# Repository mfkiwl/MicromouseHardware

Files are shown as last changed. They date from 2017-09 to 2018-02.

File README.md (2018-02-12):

# MicromouseHardware
This is the Hardware design for my micromouse. I will be participating in the UC San Diego's IEEE Micromouse competition 
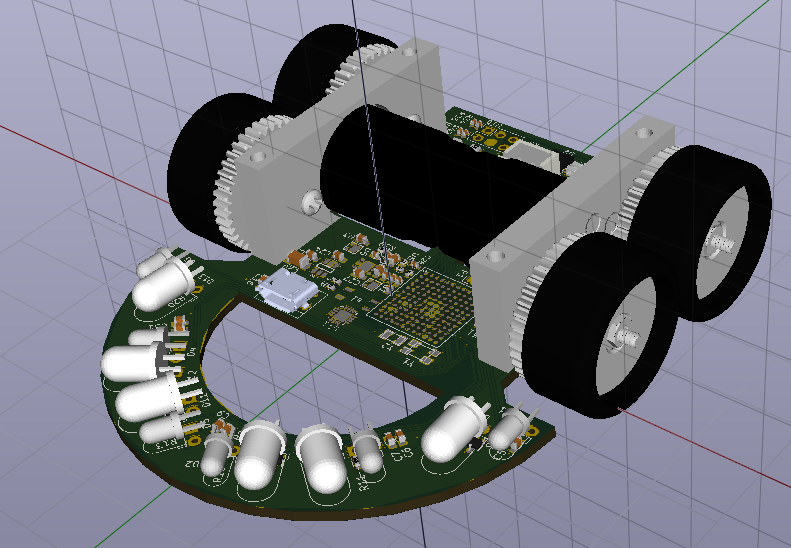
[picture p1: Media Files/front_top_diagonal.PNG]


 More images can be found [here](https://github.com/yyekalo/MicromouseHardware/tree/master/Media%20Files)

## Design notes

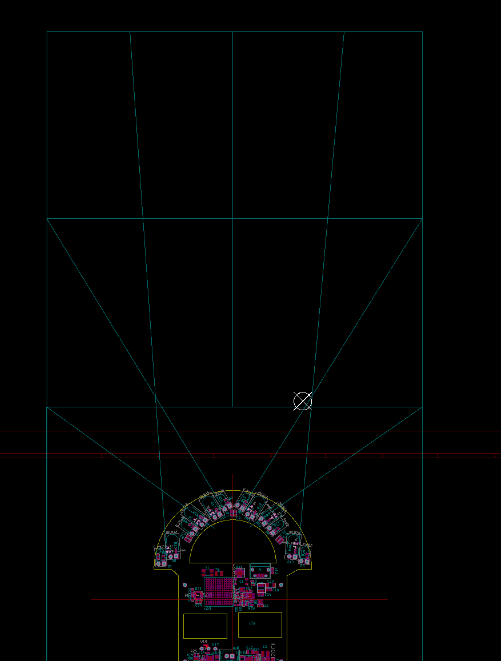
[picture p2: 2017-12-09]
IR-SENSORS direction.PNG

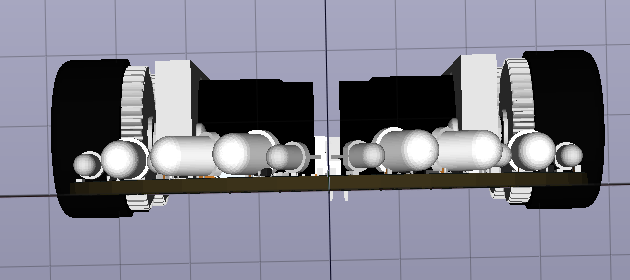
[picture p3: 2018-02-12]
Media Files/front.PNG

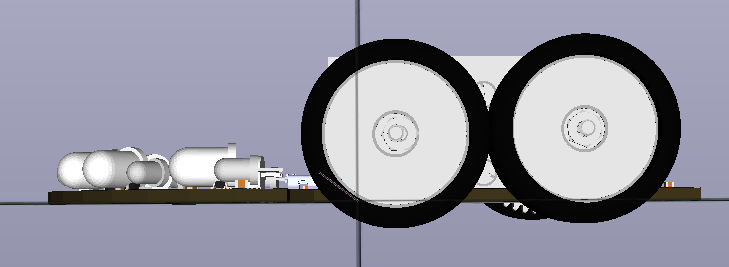
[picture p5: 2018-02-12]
Media Files/side.PNG

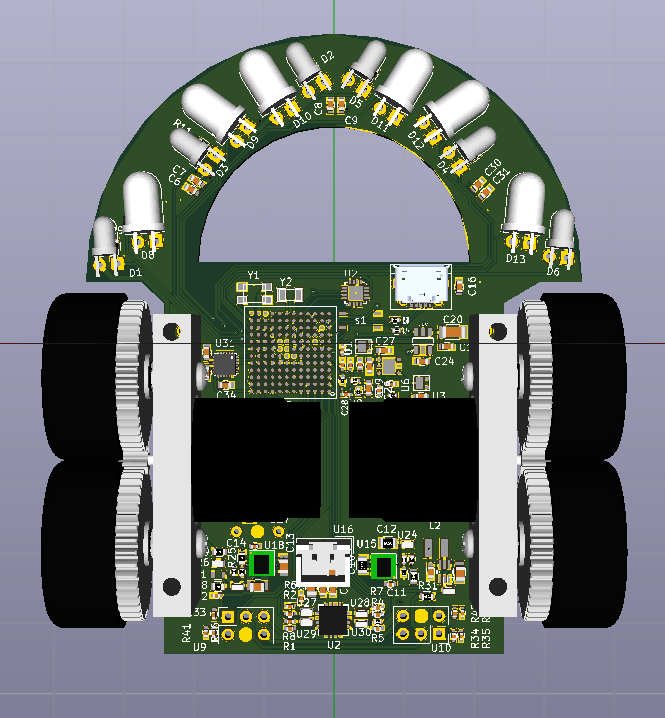
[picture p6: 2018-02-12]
Media Files/top.PNG

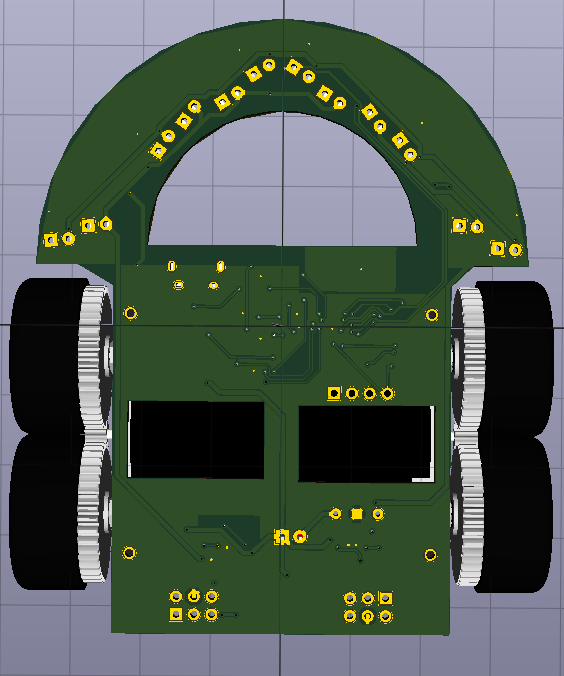
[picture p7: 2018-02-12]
Media Files/bottom.PNG

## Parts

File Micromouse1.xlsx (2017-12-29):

Proj: | None |  |  |  |  |  | Board Qty: | 100
Co.: | None |  |  |  |  |  | Total Cost: | $0.00 |  |  |  | $0.00
Date: | 2017-12-08 21:41:36 |  |  |  |  |  | Unit Cost: | $0.00 |  |  |  | 0
Global Part Info |  |  |  |  |  |  |  |  | Digi-Key
Refs | Value | Desc | Footprint | Manf | Manf# | Qty | Unit$ | Ext$ | Avail | Purch | Unit$ | Ext$ | Cat#
C1 | 100uF |  |  |  | RNE1C101MDS1PX | 0 | $0.00 | $0.00
C10 | 10uF |  | micromouse:R_0805 |  | GRM21BR60J106ME19L | 0 | $0.00 | $0.00 | 1786897 |  | $0.00 | $0.00 | 490-1718-1-ND (http://www.digikey.com/product-detail/en/murata-electronics-north-america/GRM21BR60J106ME19L/490-1718-1-ND/587425)
C11,C14 | 3300pF |  | micromouse:C_0402 |  | GRM033R70J332KA01D | 0 | $0.00 | $0.00
C12 | 22uF |  | micromouse:R_0805 |  | GRM21BC80G226ME39L | 0 | $0.00 | $0.00 | NonStk |  | $0.00 | $0.00 | 490-6464-1-ND (http://www.digikey.com/product-detail/en/murata-electronics-north-america/GRM21BC80G226ME39L/490-6464-1-ND/3845661)
C13 | 10uF |  | micromouse:C_0805 |  | GRM21BR60J106ME19L | 0 | $0.00 | $0.00 | 1786897 |  | $0.00 | $0.00 | 490-1718-1-ND (http://www.digikey.com/product-detail/en/murata-electronics-north-america/GRM21BR60J106ME19L/490-1718-1-ND/587425)
C15 | 22uF |  | micromouse:C_0805 |  | GRM21BC80G226ME39L | 0 | $0.00 | $0.00 | NonStk |  | $0.00 | $0.00 | 490-6464-1-ND (http://www.digikey.com/product-detail/en/murata-electronics-north-america/GRM21BC80G226ME39L/490-6464-1-ND/3845661)
C16,C18,C19,C24,C27,C29 | 2.2uF |  | micromouse:C_0603 |  | DNP | 0 | $0.00 | $0.00
C17,C21,C22,C26,C28 | 0.1uF |  | micromouse:C_0402 |  | DNP | 0 | $0.00 | $0.00
C2 | 10uF |  | Capacitors_SMD:C_0805 |  | C2012X5R1C106M | 0 | $0.00 | $0.00
C20 | 100uF |  | micromouse:C_1206 |  | DNP | 0 | $0.00 | $0.00
C23,C25 | 10nF |  | micromouse:C_0402 |  | DNP | 0 | $0.00 | $0.00
C3 | 0.01uF |  |  |  | GRM188R71E103KA01D | 0 | $0.00 | $0.00 | 1221077 |  | $0.00 | $0.00 | 490-1520-1-ND (http://www.digikey.com/product-detail/en/murata-electronics-north-america/GRM188R71E103KA01D/490-1520-1-ND/587861)
C32 | 10nF |  | Capacitors_SMD:C_0603 |  | DNP | 0 | $0.00 | $0.00
C35 | 2.2uF |  | Capacitors_SMD:C_0402 |  | GRM155R61A225KE95D | 0 | $0.00 | $0.00 | 31659 |  | $0.00 | $0.00 | 490-10451-1-ND (http://www.digikey.com/product-detail/en/murata-electronics-north-america/GRM155R61A225KE95D/490-10451-1-ND/5026361)
C36 | 10uF |  | Capacitors_SMD:C_0603 |  | GRM188R60J106ME47D | 0 | $0.00 | $0.00
C37 | 10uF |  | Capacitors_SMD:C_0805 |  | C0805C106K8PACTU | 0 | $0.00 | $0.00 | 1355633 |  | $0.00 | $0.00 | 399-4925-1-ND (http://www.digikey.com/product-detail/en/kemet/C0805C106K8PACTU/399-4925-1-ND/1090920)
C4 | 0.1uF |  | Capacitors_SMD:C_0603 |  | C1608X7R1E104K | 0 | $0.00 | $0.00
C5,C33 | 0.1uF |  | Capacitors_SMD:C_0603 |  | DNP | 0 | $0.00 | $0.00
C6-C9,C30,C31,C34 | C |  | Capacitors_SMD:C_0603 |  | DNP | 0 | $0.00 | $0.00
D1-D6 | ~ |  | micromouse:IR_Reciver |  | TEFT4300 | 0 | $0.00 | $0.00 | 5570 |  | $0.00 | $0.00 | 751-1041-ND (http://www.digikey.com/scripts/DkSearch/dksus.dll?WT.z_header=search_go&lang=en&keywords=TEFT4300%20)
D8-D13 | ~ |  | micromouse:IR_Emitter |  | SFH 4545 | 0 | $0.00 | $0.00
J1 | USB_B |  | micromouse:USB_Micro-B |  | DNP | 0 | $0.00 | $0.00
L1 | L |  | Inductors_SMD:L_0603 |  | BRL1608T100M | 0 | $0.00 | $0.00 | 73032 |  | $0.00 | $0.00 | 587-2895-1-ND (http://www.digikey.com/product-detail/en/taiyo-yuden/BRL1608T100M/587-2895-1-ND/2649015)
L2 | 4.7uH |  | Inductors_NEOSID:Neosid_Inductor_SM-NE29_SMD1008 |  | LQM2HPN4R7MGCL | 0 | $0.00 | $0.00 | 16254 |  | $0.00 | $0.00 | 490-7783-1-ND (http://www.digikey.com/product-detail/en/murata-electronics-north-america/LQM2HPN4R7MGCL/490-7783-1-ND/4357984)
P1 | CONN_01X4 |  | Socket_Strips:Socket_Strip_Straight_1x04_Pitch2.54mm |  | DNP | 0 | $0.00 | $0.00
Q1-Q6 | Q_NMOS_DGS |  | micromouse:DMG1012UW |  | DMG1012UW | 0 | $0.00 | $0.00 | 49178 |  | $0.00 | $0.00 | DMG1012UW-7DICT-ND (http://www.digikey.com/product-detail/en/diodes-incorporated/DMG1012UW-7/DMG1012UW-7DICT-ND/2183242)
R1,R2,R4 | 0 |  | Capacitors_SMD:C_0402 |  | MCS04020Z0000ZE000 | 0 | $0.00 | $0.00
R15-R20 | 0.75 |  | micromouse:C_0402 |  | ERJ-2BQFR75X | 0 | $0.00 | $0.00
R21 | 150K |  | micromouse:R_0402 |  | CRCW0402150KFKED | 0 | $0.00 | $0.00 | 315184 |  | $0.00 | $0.00 | 541-150KLCT-ND (http://www.digikey.com/product-detail/en/vishay-dale/CRCW0402150KFKED/541-150KLCT-ND/1183369)
R22,R26 | 10k |  | micromouse:R_0402 |  | RC0402JR-0710KL | 0 | $0.00 | $0.00 | 7483264 |  | $0.00 | $0.00 | 311-10KJRCT-ND (http://www.digikey.com/product-detail/en/yageo/RC0402JR-0710KL/311-10KJRCT-ND/729365)
R23 | 226K |  | micromouse:R_0402 |  | CRCW0402226KFKED | 0 | $0.00 | $0.00 | 4745 |  | $0.00 | $0.00 | 541-226KLCT-ND (http://www.digikey.com/product-detail/en/vishay-dale/CRCW0402226KFKED/541-226KLCT-ND/1183389)
R24,R28,R29,R31 | 0 |  | micromouse:R_0603 |  | RC0603JR-070RL | 0 | $0.00 | $0.00 | 9624530 |  | $0.00 | $0.00 | 311-0.0GRCT-ND (http://www.digikey.com/product-detail/en/yageo/RC0603JR-070RL/311-0.0GRCT-ND/729622)
R25 | 180k |  | micromouse:R_0603 |  | RC0603FR-07180KL | 0 | $0.00 | $0.00 | 669995 |  | $0.00 | $0.00 | 311-180KHRCT-ND (http://www.digikey.com/product-detail/en/yageo/RC0603FR-07180KL/311-180KHRCT-ND/729942)
R27 | 562k |  | micromouse:R_0402 |  | CRCW0402562KFKED | 0 | $0.00 | $0.00
R3 | 0 |  | micromouse:R_0402 |  | MCS04020Z0000ZE000 | 0 | $0.00 | $0.00
R32,R35,R36,R43 | R |  | Capacitors_SMD:C_0402 |  | AC0402FR-074K32L | 0 | $0.00 | $0.00 | 27880 |  | $0.00 | $0.00 | YAG5300CT-ND (http://www.digikey.com/product-detail/en/yageo/AC0402FR-074K32L/YAG5300CT-ND/7063643)
R33,R34,R41,R42 | R |  | Capacitors_SMD:C_0402 |  | RC0402FR-072K43L | 0 | $0.00 | $0.00 | 56754 |  | $0.00 | $0.00 | YAG3101CT-ND (http://www.digikey.com/product-detail/en/yageo/RC0402FR-072K43L/YAG3101CT-ND/5281966)
R37,R38 | 33 |  | Resistors_SMD:R_0402 |  | DNP | 0 | $0.00 | $0.00
R39 | 470 |  | micromouse:R_0402 |  | DNP | 0 | $0.00 | $0.00
R40 | 100k |  | micromouse:R_0402 |  | DNP | 0 | $0.00 | $0.00
R5-R8 | 47k |  | Capacitors_SMD:C_0402 |  | RC0402JR-074K7L | 0 | $0.00 | $0.00 | 1733222 |  | $0.00 | $0.00 | 311-4.7KJRCT-ND (http://www.digikey.com/product-detail/en/yageo/RC0402JR-074K7L/311-4.7KJRCT-ND/729424)
R9-R14 | 1.8k |  | Resistors_SMD:R_0603 |  | DNP | 0 | $0.00 | $0.00
U1,U6 | BAT54C |  | micromouse:PMEG4010_DIODE |  | DNP | 0 | $0.00 | $0.00
U15,U18 | LMZ21701 |  | micromouse:LMZ21701 |  | LMZ21701SILR | 0 | $0.00 | $0.00 | 49808 |  | $0.00 | $0.00 | 296-43645-1-ND (http://www.digikey.com/product-detail/en/texas-instruments/LMZ21701SILR/296-43645-1-ND/5864795)
U16 | JST_Connector |  | micromouse:JST_Connector |  | DNP | 0 | $0.00 | $0.00
U17 | Switch_micromouse |  | micromouse:Switch_battery |  | DNP | 0 | $0.00 | $0.00
U19 | splitter |  | micromouse:spliter |  | DNP | 0 | $0.00 | $0.00
U2 | DRV8833 |  | micromouse:DRV8833 |  | DRV8833RTYT | 0 | $0.00 | $0.00 | 11089 |  | $0.00 | $0.00 | 296-29398-1-ND (http://www.digikey.com/product-detail/en/texas-instruments/DRV8833RTYR/296-29398-1-ND/2741750)
U20 | TPD3S014 |  | micromouse:TPD3S014 |  | DNP | 0 | $0.00 | $0.00
U21 | MKL02Z32VFG4 |  | micromouse:MKL02Z32VFG4 |  | DNP | 0 | $0.00 | $0.00
U22 | LP38691 |  | micromouse:LP38691 |  | DNP | 0 | $0.00 | $0.00
U23 | MK66FX1M0 |  | micromouse:Microcontroller |  | DNP | 0 | $0.00 | $0.00
U3 | 120 |  | micromouse:C_0603 |  | DNP | 0 | $0.00 | $0.00
U31 | MPU-6500 |  | micromouse:MPU-6500 |  | MPU-6500 | 0 | $0.00 | $0.00
U32 | Motor_mount |  | micromouse:Motor_mount |  | DNP | 0 | $0.00 | $0.00
U4 | TPS61222DCK |  | micromouse:TPS61222DCK |  | TPS61222DCK | 0 | $0.00 | $0.00 | 113788 |  | $0.00 | $0.00 | 296-39435-1-ND (http://www.digikey.com/product-detail/en/texas-instruments/TPS61222DCKR/296-39435-1-ND/5143383)
U5,U14 | 600 |  | micromouse:R_0402 |  | DNP | 0 | $0.00 | $0.00
U7,U24-U30 | Test_Point |  | micromouse:Test_Point |  | RCU-0C | 0 | $0.00 | $0.00 | 147710 |  | $0.00 | $0.00 | A106145CT-ND (http://www.digikey.com/product-detail/en/te-connectivity-amp-connectors/RCU-0C/A106145CT-ND/3477802)
U9,U10 | CONN_02X03 |  |  |  | M20-9980346 | 0 | $0.00 | $0.00 | 34609 |  | $0.00 | $0.00 | 952-2121-ND (http://www.digikey.com/scripts/DkSearch/dksus.dll?WT.z_header=search_go&lang=en)
Y1 | Crystal_16MHz |  | micromouse:16Mhz_crystal |  | DNP | 0 | $0.00 | $0.00
Y2 | 32.768MHz |  | micromouse:32.768_CRYSTAL |  | DNP | 0 | $0.00 | $0.00
s1 | Switch |  | micromouse:Switch_teensy |  | DNP | 0 | $0.00 | $0.00
 |  |  |  |  |  |  |  |  |  | 0
 |  |  |  |  |  |  |  |  |  | 0 | 0 | 0
 |  |  |  |  |  |  |  |  |  | 0 | 0 | 0
 |  |  |  |  |  |  |  |  |  | 0 | 0 | 0
 |  |  |  |  |  |  |  |  |  | 0 | 0 | 0
 |  |  |  |  |  |  |  |  |  | 0 | 0 | 0
 |  |  |  |  |  |  |  |  |  | 0 | 0 | 0
 |  |  |  |  |  |  |  |  |  | 0 | 0 | 0
 |  |  |  |  |  |  |  |  |  | 0 | 0 | 0
 |  |  |  |  |  |  |  |  |  | 0 | 0 | 0
 |  |  |  |  |  |  |  |  |  | 0 | 0 | 0
 |  |  |  |  |  |  |  |  |  | 0 | 0 | 0
 |  |  |  |  |  |  |  |  |  | 0 | 0 | 0
 |  |  |  |  |  |  |  |  |  | 0 | 0 | 0
 |  |  |  |  |  |  |  |  |  | 0 | 0 | 0
 |  |  |  |  |  |  |  |  |  | 0 | 0 | 0
 |  |  |  |  |  |  |  |  |  | 0 | 0 | 0
 |  |  |  |  |  |  |  |  |  | 0 | 0 | 0
 |  |  |  |  |  |  |  |  |  | 0 | 0 | 0
 |  |  |  |  |  |  |  |  |  | 0 | 0 | 0
 |  |  |  |  |  |  |  |  |  | 0 | 0 | 0
 |  |  |  |  |  |  |  |  |  | 0 | 0 | 0
 |  |  |  |  |  |  |  |  |  | 0 | 0 | 0
 |  |  |  |  |  |  |  |  |  | 0 | 0 | 0
 |  |  |  |  |  |  |  |  |  | 0 | 0 | 0
 |  |  |  |  |  |  |  |  |  | 0 | 0 | 0
 |  |  |  |  |  |  |  |  |  | 0 | 0 | 0
 |  |  |  |  |  |  |  |  |  | 0 | 0 | 0
 |  |  |  |  |  |  |  |  |  | 0 | 0 | 0
 |  |  |  |  |  |  |  |  |  | 0 | 0 | 0
 |  |  |  |  |  |  |  |  |  | 0 | 0 | 0
 |  |  |  |  |  |  |  |  |  | 0 | 0 | 0
 |  |  |  |  |  |  |  |  |  | 0 | 0 | 0
 |  |  |  |  |  |  |  |  |  | 0 | 0 | 0
 |  |  |  |  |  |  |  |  |  | 0 | 0 | 0
 |  |  |  |  |  |  |  |  |  | 0 | 0 | 0
 |  |  |  |  |  |  |  |  |  | 0 | 0 | 0
 |  |  |  |  |  |  |  |  |  | 0 | 0 | 0
 |  |  |  |  |  |  |  |  |  | 0 | 0 | 0
 |  |  |  |  |  |  |  |  |  | 0 | 0 | 0
 |  |  |  |  |  |  |  |  |  | 0 | 0 | 0
 |  |  |  |  |  |  |  |  |  | 0 | 0 | 0
 |  |  |  |  |  |  |  |  |  | 0 | 0 | 0
 |  |  |  |  |  |  |  |  |  | 0 | 0 | 0
 |  |  |  |  |  |  |  |  |  | 0 | 0 | 0
 |  |  |  |  |  |  |  |  |  | 0 | 0 | 0
 |  |  |  |  |  |  |  |  |  | 0 | 0 | 0
 |  |  |  |  |  |  |  |  |  | 0 | 0 | 0
 |  |  |  |  |  |  |  |  |  | 0 | 0 | 0
 |  |  |  |  |  |  |  |  |  | 0 | 0 | 0
 |  |  |  |  |  |  |  |  |  | 0 | 0 | 0
 |  |  |  |  |  |  |  |  |  | 0 | 0 | 0
 |  |  |  |  |  |  |  |  |  | 0 | 0 | 0
 |  |  |  |  |  |  |  |  |  | 0 | 0 | 0
 |  |  |  |  |  |  |  |  |  | 0 | 0 | 0
 |  |  |  |  |  |  |  |  |  | 0 | 0 | 0
 |  |  |  |  |  |  |  |  |  | 0 | 0 | 0
 |  |  |  |  |  |  |  |  |  | 0 | 0 | 0
 |  |  |  |  |  |  |  |  |  | 0 | 0 | 0
 |  |  |  |  |  |  |  |  |  | 0 | 0 | 0
 |  |  |  |  |  |  |  |  |  | 0 | 0 | 0
 |  |  |  |  |  |  |  |  |  | 0 | 0 | 0
 |  |  |  |  |  |  |  |  |  | 0 | 0 | 0

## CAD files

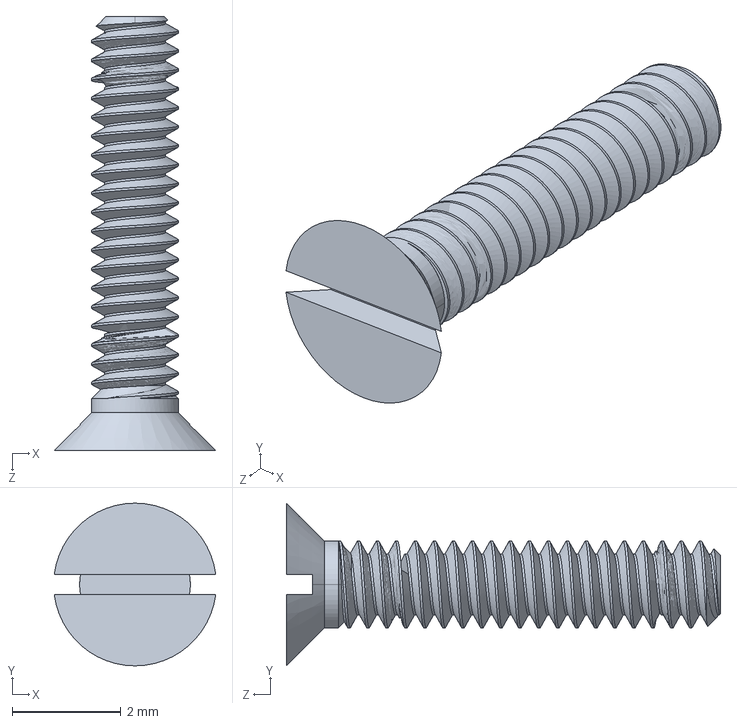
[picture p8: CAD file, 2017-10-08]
Micromouse 3D model/M1.6x8_FlatHead_forMotor.STEP
2.98 x 3.00 x 8.00 mm

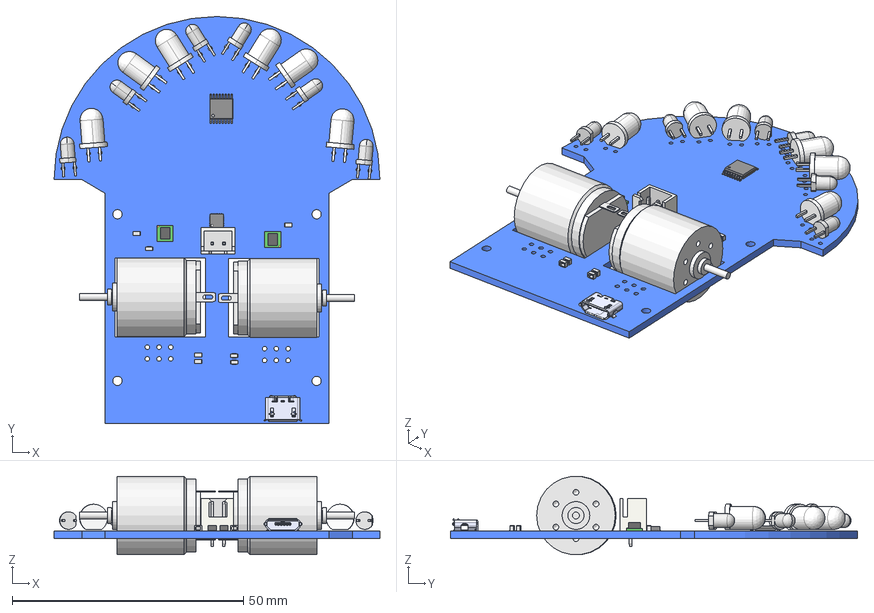
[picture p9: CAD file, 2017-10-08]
Micromouse1.21.step
70.4 x 87.9 x 16.9 mm
Pcb
1717TSR_
1717TSR_001
IR_Emitter_
IR_Emitter_001
IR_Emitter_002
IR_Emitter_003
IR_Emitter_004
IR_Emitter_005
IR_Reciver_
IR_Reciver_001
IR_Reciver_002
IR_Reciver_003
IR_Reciver_004
IR_Reciver_005
MPU_6500_
User_Library-MicroUSB-B_Molex_105017-0001_
JST_2x1_CONNECTOR_
1422594_rcu-0c_
1422594_rcu-0c_001
1422594_rcu-0c_002
1422594_rcu-0c_003
1422594_rcu-0c_004
1422594_rcu-0c_005
1422594_rcu-0c_006
User_Library-SIL0008E-1_
User_Library-SIL0008E-1_001
User_Library-TSSOP-16-1_

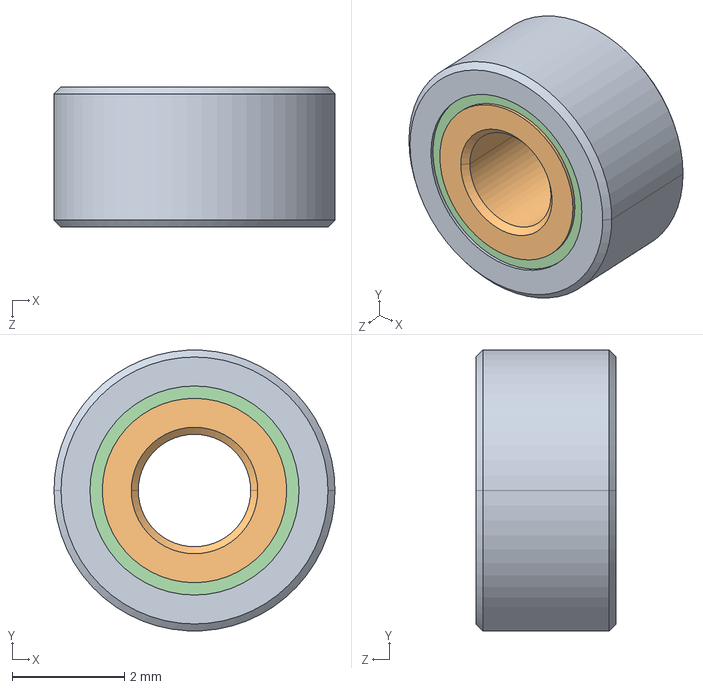
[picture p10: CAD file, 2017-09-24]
Micromouse 3D model/2x5x2.5BallBearing.STEP
5.00 x 4.99 x 2.50 mm

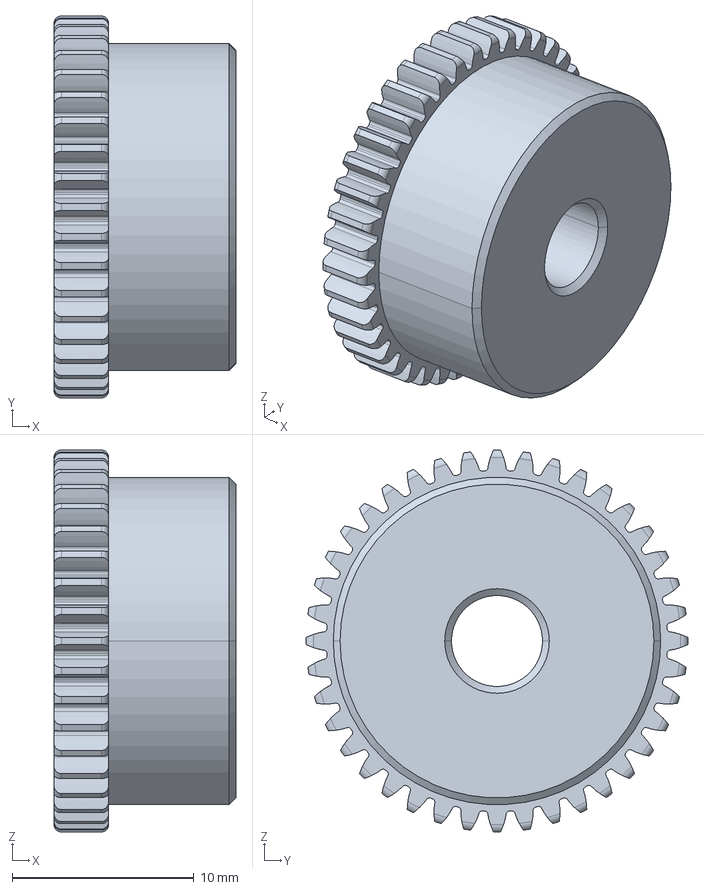
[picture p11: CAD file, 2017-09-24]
Micromouse 3D model/spur_gear_wheel_40T_stp.stp
10.0 x 21.0 x 21.0 mm

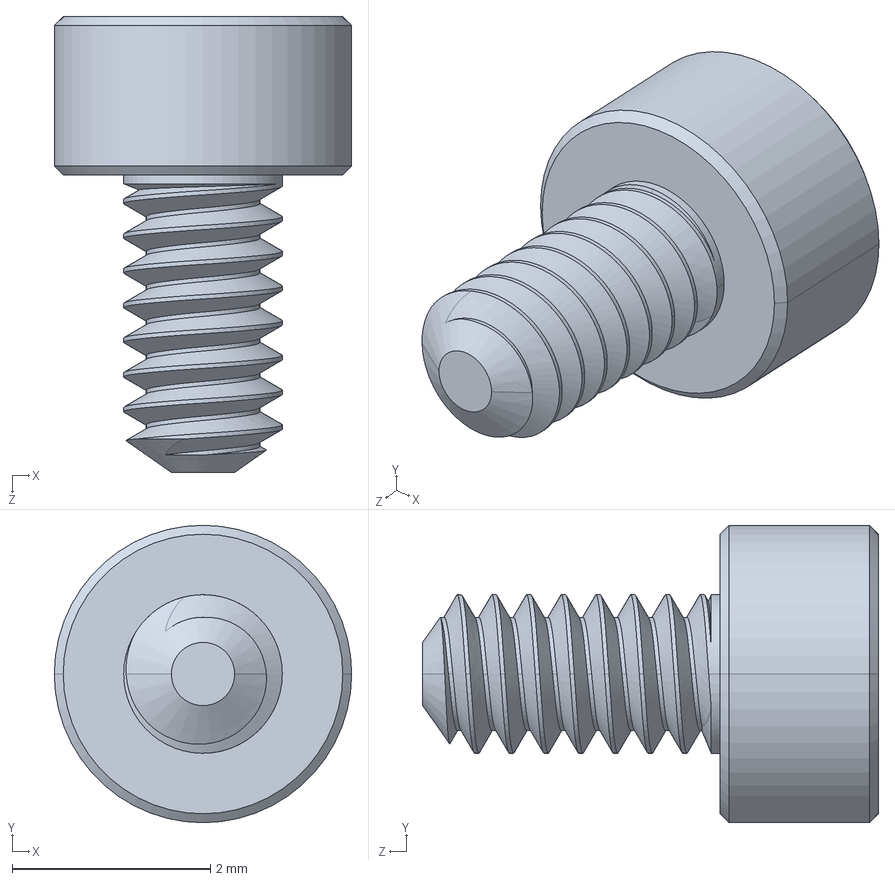
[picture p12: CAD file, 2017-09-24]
Micromouse 3D model/M1.6x3mm_motor_mounters.STEP
3.00 x 3.00 x 4.60 mm

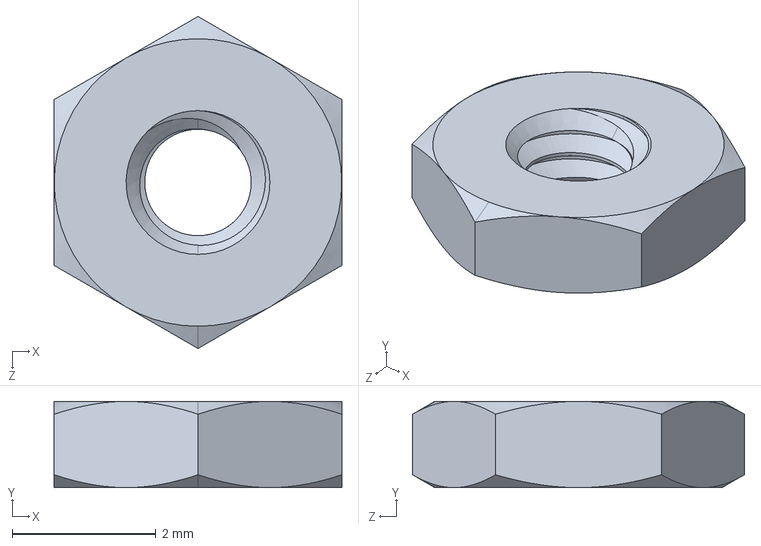
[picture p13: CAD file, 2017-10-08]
Micromouse 3D model/M2x1.2nut.STEP
4.00 x 1.20 x 4.62 mm

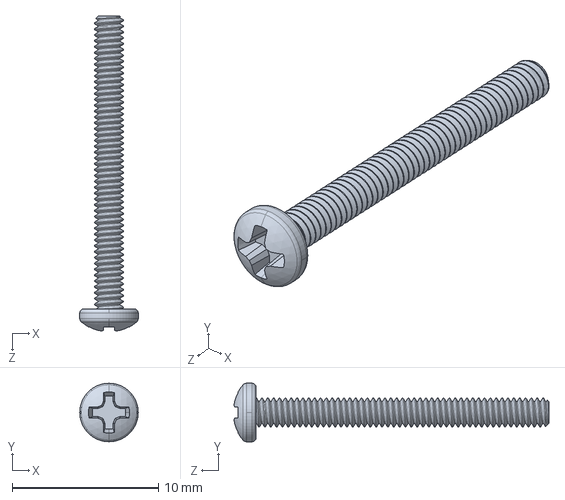
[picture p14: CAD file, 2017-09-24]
Micromouse 3D model/M2x20mm_ PHILLIPS.STEP
4.00 x 4.00 x 21.5 mm

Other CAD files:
Micromouse1_2.FCStd
Micromouse1.2.step
Micromouse 3D model/Micromouse 3D.dwg
Micromouse 3D model/Motor.dwg
Micromouse 3D model/2x5x2.5BallBearing.ipt
Micromouse 3D model/2x5x2.5BallBearingFlanged.ipt
Micromouse 3D model/2x5x2.5BallBearingFlanged_MIR.ipt
Micromouse 3D model/2x5x2.5BallBearing_MIR.ipt
Micromouse 3D model/M1.6x8_FlatHead_forMotor.ipt
Micromouse 3D model/M1.6x8_FlatHead_forMotor_MIR.ipt
Micromouse 3D model/M2x1.2nut.ipt
Micromouse 3D model/M2x1.2nut_MIR.ipt
Micromouse 3D model/M2x1.2nut_MIR_MIR.ipt
Micromouse 3D model/M2x1.2nut_MIR_MIR1.ipt
Micromouse 3D model/M2x20mm_ PHILLIPS.ipt
Micromouse 3D model/M2x20mm_ PHILLIPS_MIR.ipt
Micromouse 3D model/Micromouse1.2.kicad_pcb.ipt
Micromouse 3D model/MicromouseAssembly.iam
Micromouse 3D model/Micromouse_pcb.ipt
Micromouse 3D model/OldVersions/2x5x2.5BallBearing.0001.ipt
Micromouse 3D model/OldVersions/2x5x2.5BallBearing.0002.ipt
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

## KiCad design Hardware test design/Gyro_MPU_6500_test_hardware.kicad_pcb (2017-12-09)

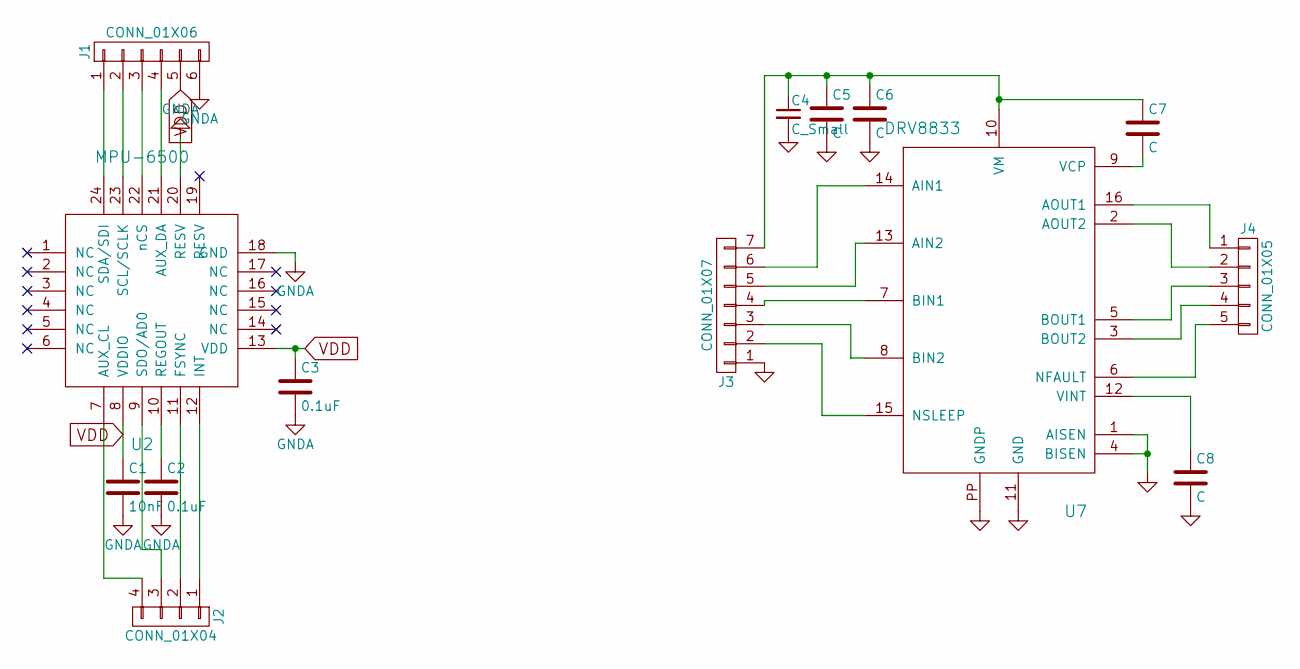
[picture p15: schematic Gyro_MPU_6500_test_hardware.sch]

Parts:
C1: 10nF; C_0603
C2, C3: 0.1uF; C_0603
C4: C_Small; CP_Radial_D5.0mm_P2.00mm
C5, C6, C7, C8: C; C_0603
J1: CONN_01X06; JST_EH_B06B-EH-A_06x2.50mm_Straight
J2: CONN_01X04; HDRV4W25P254_4X1_1016X254H1135
J3: CONN_01X07; JST_EH_B07B-EH-A_07x2.50mm_Straight
J4: CONN_01X05; JST_EH_B05B-EH-A_05x2.50mm_Straight
U2: MPU-6500
U7: DRV8833

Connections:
GNDA: C1.2, C2.2, C3.2, C4.2, C5.2, C6.2, C8.2, J1.6, J3.1, U2.18 (GND), U2.20 (RESV), U7.1 (AISEN), U7.4 (BISEN), U7.11 (GND), U7.PP (GNDP)
unnamed: C2.1, U2.10 (REGOUT)
unnamed: C4.1, C5.1, C6.1, C7.1, J3.7, U7.10 (VM)
unnamed: C7.2, U7.9 (VCP)
unnamed: C8.1, U7.12 (VINT)
unnamed: J1.1, U2.24 (SDA/SDI)
unnamed: J1.2, U2.23 (SCL/SCLK)
unnamed: J1.3, U2.22 (nCS)
unnamed: J1.4, U2.21 (AUX_DA)
unnamed: J2.1, U2.12 (INT)
unnamed: J2.2, U2.11 (FSYNC)
unnamed: J2.3, U2.9 (SDO/AD0)
unnamed: J2.4, U2.7 (AUX_CL)
unnamed: J3.2, U7.15 (NSLEEP)
unnamed: J3.3, U7.8 (BIN2)
unnamed: J3.4, U7.7 (BIN1)
unnamed: J3.5, U7.13 (AIN2)
unnamed: J3.6, U7.14 (AIN1)
unnamed: J4.1, U7.16 (AOUT1)
unnamed: J4.2, U7.2 (AOUT2)
unnamed: J4.3, U7.5 (BOUT1)
unnamed: J4.4, U7.3 (BOUT2)
unnamed: J4.5, U7.6 (NFAULT)
VDD: C1.1, C3.1, J1.5, U2.8 (VDDIO), U2.13 (VDD)

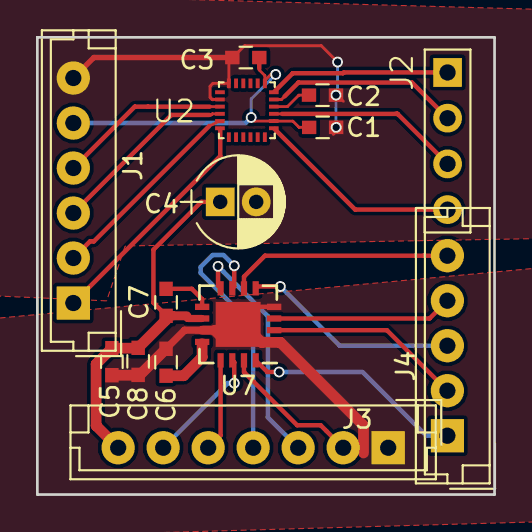
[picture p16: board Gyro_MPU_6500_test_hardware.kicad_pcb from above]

Board: 2 copper layers, 25.4 x 25.4 mm, 14 parts (0 on the bottom side), 24 nets.

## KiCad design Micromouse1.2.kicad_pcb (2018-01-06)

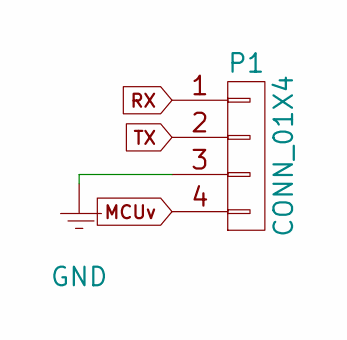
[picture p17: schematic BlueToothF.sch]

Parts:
P1: CONN_01X4; Socket_Strip_Straight_1x04_Pitch2.54mm

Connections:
MCUv: P1.4; also elsewhere on the board
RX: P1.1; also elsewhere on the board
TX: P1.2; also elsewhere on the board

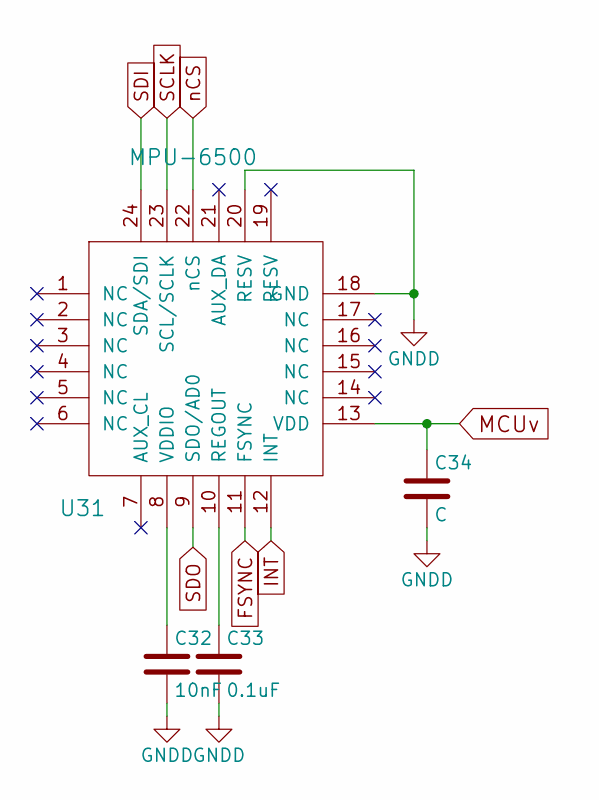
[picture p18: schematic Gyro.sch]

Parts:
C32: 10nF; C_0603
C33: 0.1uF; C_0603
C34: C; C_0603
U31: MPU-6500

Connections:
FSYNC: U31.11 (FSYNC); also elsewhere on the board
GNDD: C32.2, C33.2, C34.2, U31.18 (GND), U31.20 (RESV); also elsewhere on the board
INT: U31.12 (INT); also elsewhere on the board
MCUv: C34.1, U31.13 (VDD); also elsewhere on the board
unnamed: C32.1, U31.8 (VDDIO)
unnamed: C33.1, U31.10 (REGOUT)
SCLK: U31.23 (SCL/SCLK); also elsewhere on the board
SDI: U31.24 (SDA/SDI); also elsewhere on the board
SDO: U31.9 (SDO/AD0); also elsewhere on the board
nCS: U31.22 (nCS); also elsewhere on the board

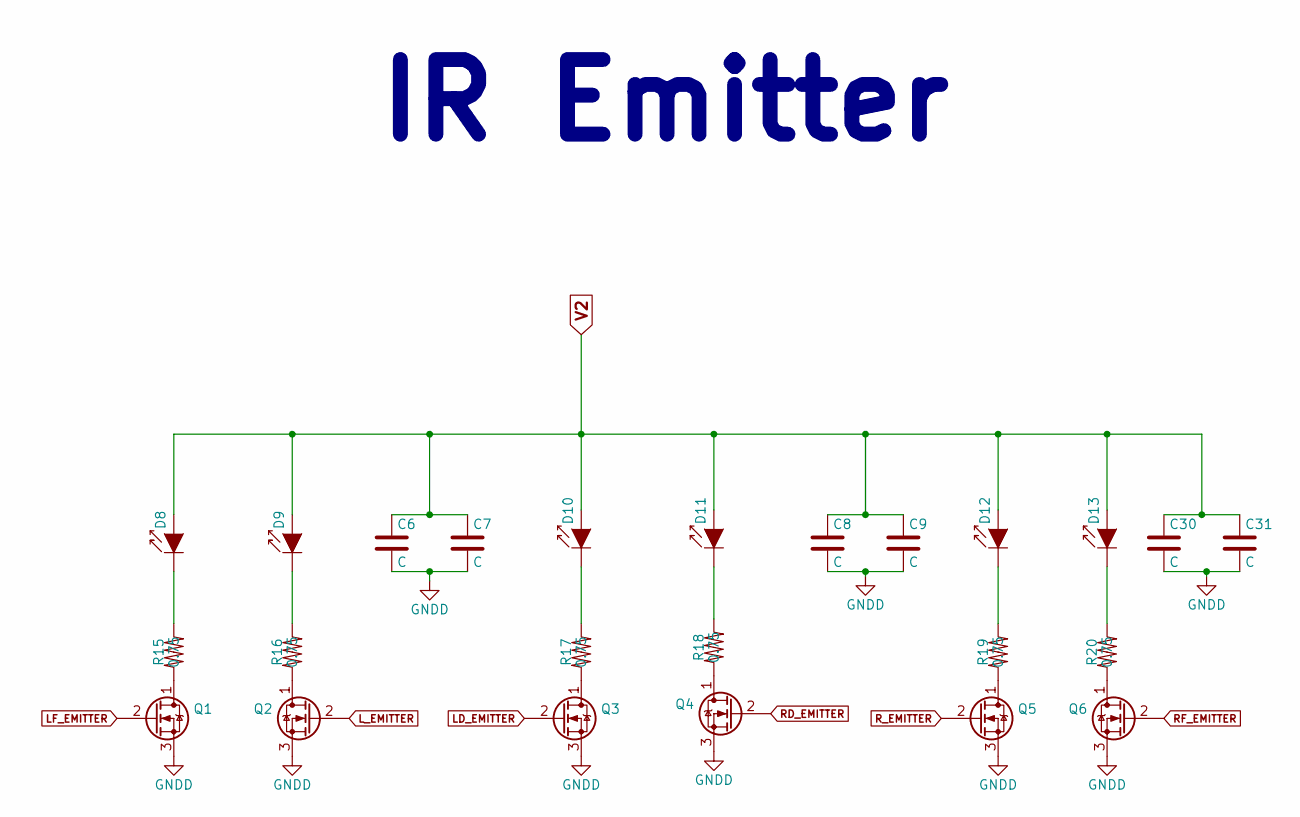
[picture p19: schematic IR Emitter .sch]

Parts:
C6, C7, C8, C9, C30, C31: C; C_0603
D8, D9, D10, D11, D12, D13: IR_Emitter
Q1, Q2, Q3, Q4, Q5, Q6: Q_NMOS_DGS; DMG1012UW
R15, R16, R17, R18, R19, R20: 0.75; C_0402

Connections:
GNDD: C6.2, C7.2, C8.2, C9.2, C30.2, C31.2, Q1.3 (S), Q2.3 (S), Q3.3 (S), Q4.3 (S), Q5.3 (S), Q6.3 (S); also elsewhere on the board
LD_EMITTER: Q3.2 (G); also elsewhere on the board
LF_EMITTER: Q1.2 (G); also elsewhere on the board
L_EMITTER: Q2.2 (G); also elsewhere on the board
unnamed: D8.1 (K), R15.2
unnamed: D9.1 (K), R16.2
unnamed: D10.1 (K), R17.2
unnamed: D11.1 (K), R18.2
unnamed: D12.1 (K), R19.2
unnamed: D13.1 (K), R20.2
unnamed: Q1.1 (D), R15.1
unnamed: Q2.1 (D), R16.1
unnamed: Q3.1 (D), R17.1
unnamed: Q4.1 (D), R18.1
unnamed: Q5.1 (D), R19.1
unnamed: Q6.1 (D), R20.1
RD_EMITTER: Q4.2 (G); also elsewhere on the board
RF_EMITTER: Q6.2 (G); also elsewhere on the board
R_EMITTER: Q5.2 (G); also elsewhere on the board
V2: C6.1, C7.1, C8.1, C9.1, C30.1, C31.1, D8.2 (A), D9.2 (A), D10.2 (A), D11.2 (A), D12.2 (A), D13.2 (A); also elsewhere on the board

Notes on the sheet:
IR Emitter

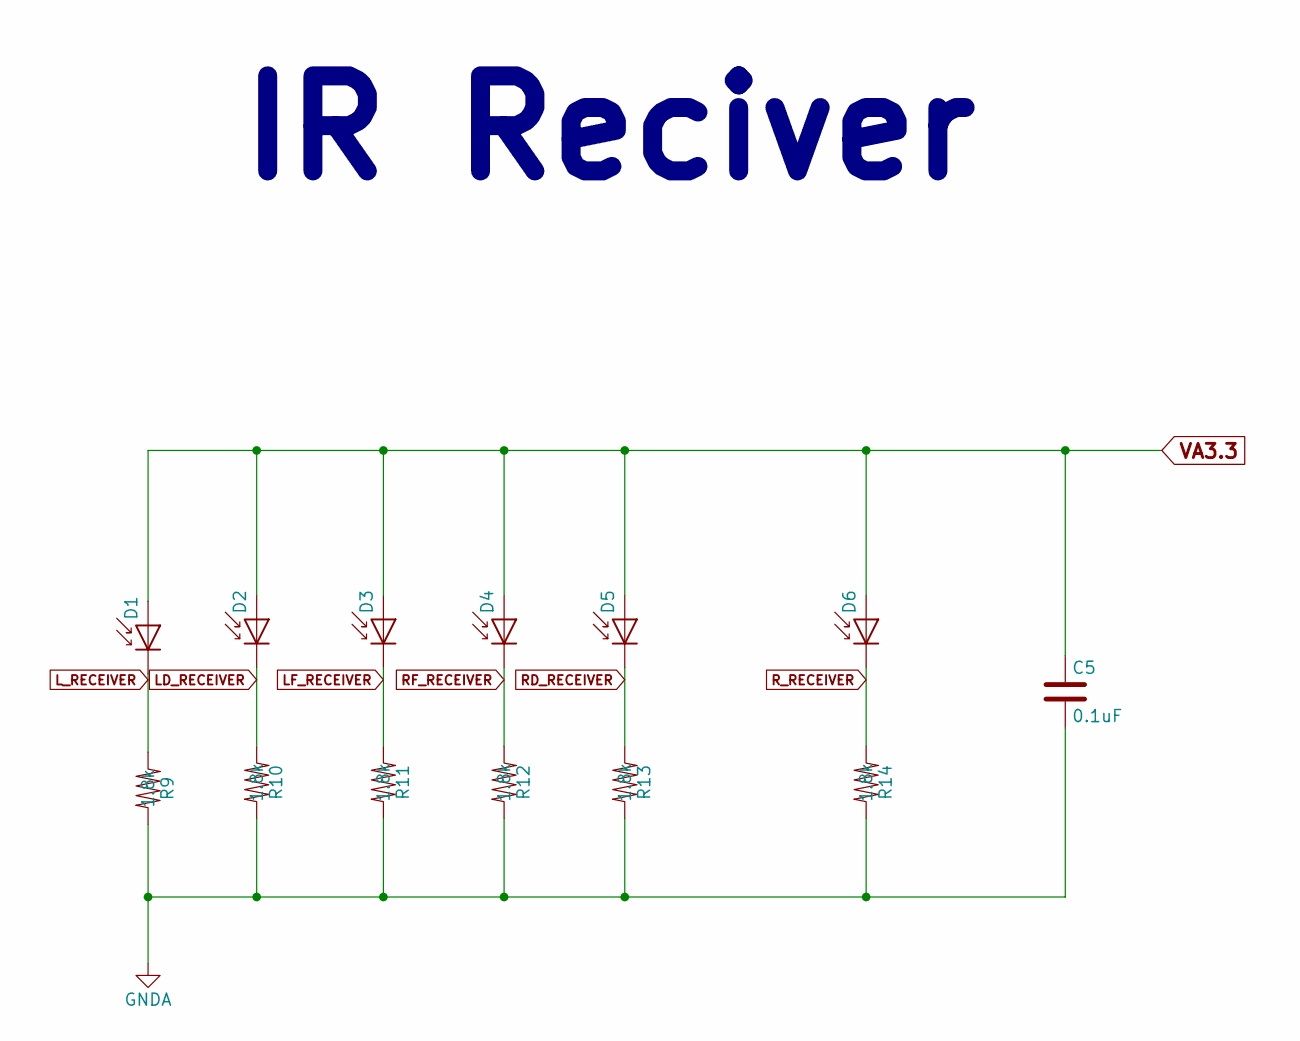
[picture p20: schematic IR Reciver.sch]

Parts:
C5: 0.1uF; C_0603
D1, D2, D3, D4, D5, D6: IR_Reciver
R9, R10, R11, R12, R13, R14: 1.8k; R_0603

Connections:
GNDA: C5.2, R9.2, R10.2, R11.2, R12.2, R13.2, R14.2; also elsewhere on the board
LD_RECEIVER: D2.1 (K), R10.1; also elsewhere on the board
LF_RECEIVER: D3.1 (K), R11.1; also elsewhere on the board
L_RECEIVER: D1.1 (K), R9.1; also elsewhere on the board
RD_RECEIVER: D5.1 (K), R13.1; also elsewhere on the board
RF_RECEIVER: D4.1 (K), R12.1; also elsewhere on the board
R_RECEIVER: D6.1 (K), R14.1; also elsewhere on the board
VA3.3: C5.1, D1.2 (A), D2.2 (A), D3.2 (A), D4.2 (A), D5.2 (A), D6.2 (A); also elsewhere on the board

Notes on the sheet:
IR Reciver

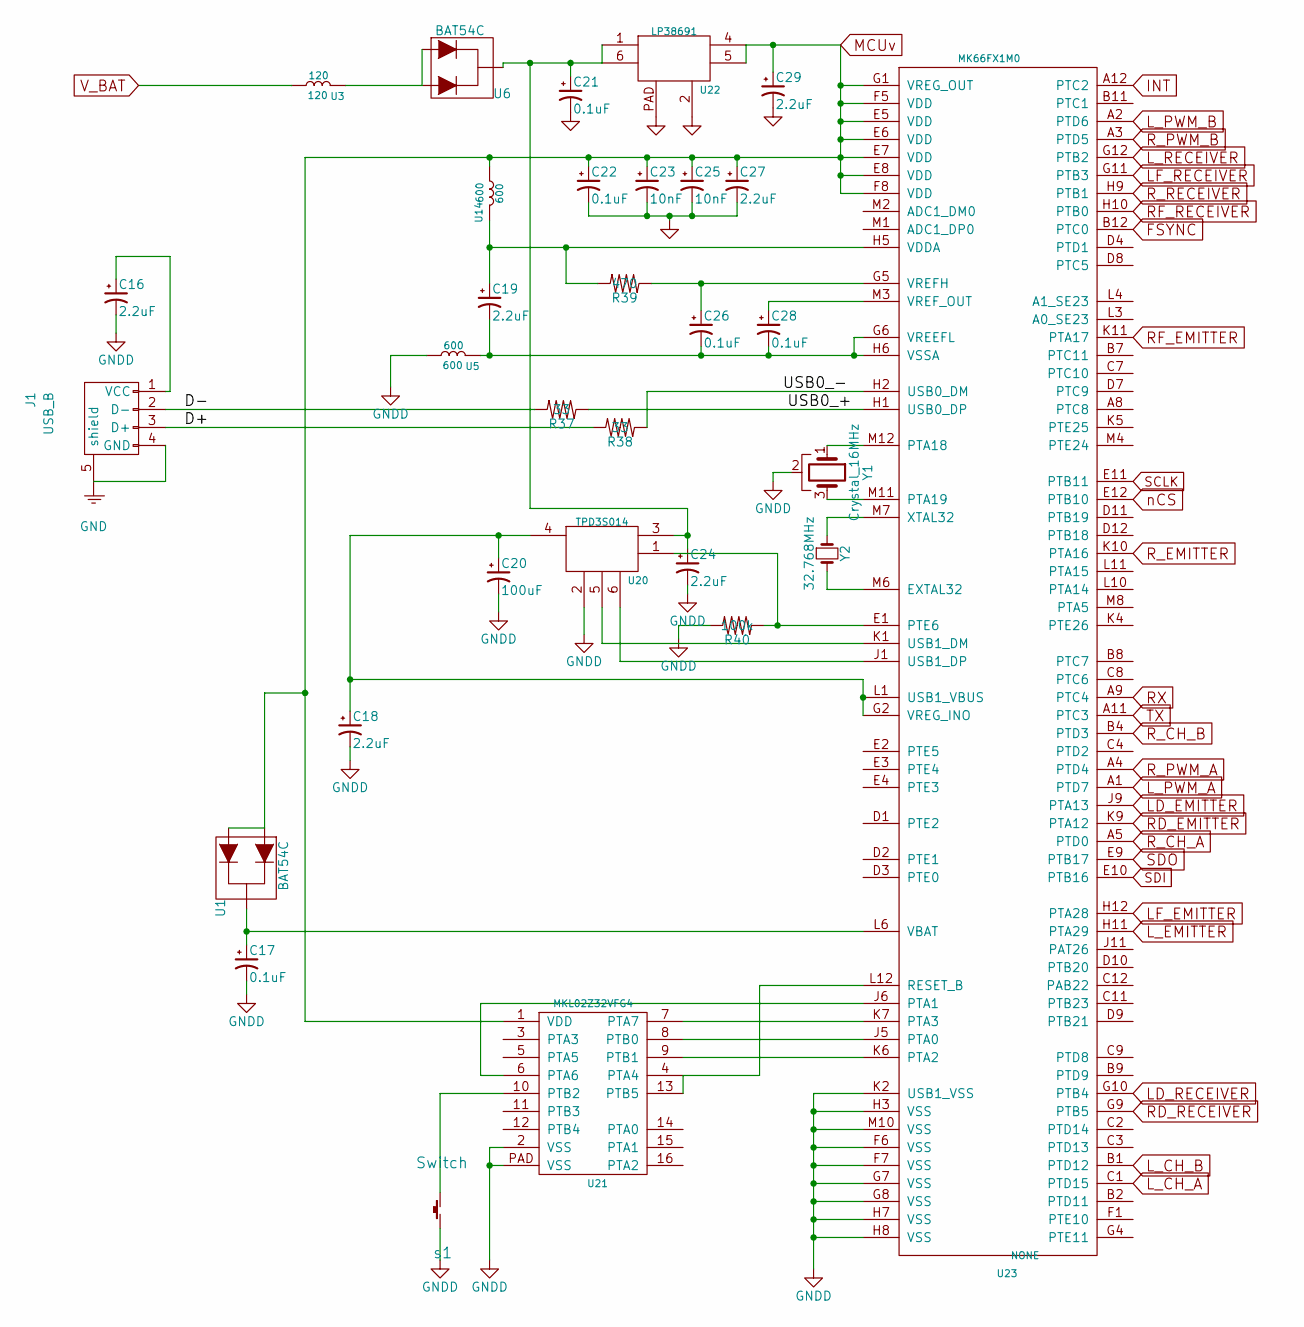
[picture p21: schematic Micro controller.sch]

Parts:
C16, C18, C19, C24, C27, C29: 2.2uF; C_0603
C17, C21, C22, C26, C28: 0.1uF; C_0402
C20: 100uF; C_1206
C23, C25: 10nF; C_0402
J1: USB_B; USB_Micro-B
R37, R38: 33; R_0402
R39: 470; R_0402
R40: 100k; R_0402
U1, U6: BAT54C; PMEG4010_DIODE
U3: 120; C_0603
U5, U14: 600; R_0402
U20: TPD3S014
U21: MKL02Z32VFG4
U22: LP38691
U23: MK66FX1M0; Microcontroller
Y1: Crystal_16MHz; 16Mhz_crystal
Y2: 32.768MHz; 32.768_CRYSTAL
s1: Switch; Switch_teensy

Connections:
/Micro controller/D+: J1.3 (D+), R38.2
/Micro controller/D-: J1.2 (D-), R37.2
/Micro controller/USB0_+: R37.1, U23.H1 (USB0_DP)
/Micro controller/USB0_-: R38.1, U23.H2 (USB0_DM)
FSYNC: U23.B12 (PTC0); also elsewhere on the board
GNDD: C16.2, C17.2, C18.2, C20.2, C21.2, C22.2, C23.2, C24.2, C25.2, C27.2, C29.2, R40.2, U5.1, U20.2, U21.2 (VSS), U21.PAD (VSS), U22.2, U22.PAD, U23.F6 (VSS), U23.F7 (VSS), U23.G7 (VSS), U23.G8 (VSS), U23.H3 (VSS), U23.H7 (VSS), U23.H8 (VSS), U23.K2 (USB1_VSS), U23.M10 (VSS), Y1.2, s1.2; also elsewhere on the board
INT: U23.A12 (PTC2); also elsewhere on the board
LD_EMITTER: U23.J9 (PTA13); also elsewhere on the board
LD_RECEIVER: U23.G10 (PTB4); also elsewhere on the board
LF_EMITTER: U23.H12 (PTA28); also elsewhere on the board
LF_RECEIVER: U23.G11 (PTB3); also elsewhere on the board
L_CH_A: U23.C1 (PTD15); also elsewhere on the board
L_CH_B: U23.B1 (PTD12); also elsewhere on the board
L_EMITTER: U23.H11 (PTA29); also elsewhere on the board
L_PWM_A: U23.A1 (PTD7); also elsewhere on the board
L_PWM_B: U23.A2 (PTD6); also elsewhere on the board
L_RECEIVER: U23.G12 (PTB2); also elsewhere on the board
MCUv: C22.1, C23.1, C25.1, C27.1, C29.1, U1.1 (A), U1.2 (A), U14.1, U21.1 (VDD), U22.4, U22.5, U23.E5 (VDD), U23.E6 (VDD), U23.E7 (VDD), U23.E8 (VDD), U23.F5 (VDD), U23.F8 (VDD), U23.G1 (VREG_OUT); also elsewhere on the board
unnamed: C16.1, J1.1 (VCC)
unnamed: C17.1, U1.3, U23.L6 (VBAT)
unnamed: C18.1, C20.1, U20.4, U23.G2 (VREG_INO), U23.L1 (USB1_VBUS)
unnamed: C19.1, R39.2, U14.2, U23.H5 (VDDA)
unnamed: C19.2, C26.2, C28.2, U5.2, U23.G6 (VREEFL), U23.H6 (VSSA)
unnamed: C21.1, C24.1, U6.3, U20.3, U22.1, U22.6
unnamed: C26.1, R39.1, U23.G5 (VREFH)
unnamed: C28.1, U23.M3 (VREF_OUT)
unnamed: J1.4 (GND), J1.5 (shield)
unnamed: R40.1, U20.1, U23.E1 (PTE6)
unnamed: U3.2, U6.1 (A), U6.2 (A)
unnamed: U20.5, U23.K1 (USB1_DM)
unnamed: U20.6, U23.J1 (USB1_DP)
unnamed: U21.6 (PTA6), U23.J6 (PTA1)
unnamed: U21.7 (PTA7), U23.K7 (PTA3)
unnamed: U21.8 (PTB0), U23.J5 (PTA0)
unnamed: U21.9 (PTB1), U23.K6 (PTA2)
unnamed: U21.10 (PTB2), s1.1
unnamed: U21.4 (PTA4), U21.13 (PTB5), U23.L12 (RESET_B)
unnamed: U23.M6 (EXTAL32), Y2.2
unnamed: U23.M7 (XTAL32), Y2.1
unnamed: U23.M11 (PTA19), Y1.3
unnamed: U23.M12 (PTA18), Y1.1
RD_EMITTER: U23.K9 (PTA12); also elsewhere on the board
RD_RECEIVER: U23.G9 (PTB5); also elsewhere on the board
RF_EMITTER: U23.K11 (PTA17); also elsewhere on the board
RF_RECEIVER: U23.H10 (PTB0); also elsewhere on the board
RX: U23.A9 (PTC4); also elsewhere on the board
R_CH_A: U23.A5 (PTD0); also elsewhere on the board
R_CH_B: U23.B4 (PTD3); also elsewhere on the board
R_EMITTER: U23.K10 (PTA16); also elsewhere on the board
R_PWM_A: U23.A4 (PTD4); also elsewhere on the board
R_PWM_B: U23.A3 (PTD5); also elsewhere on the board
R_RECEIVER: U23.H9 (PTB1); also elsewhere on the board
SCLK: U23.E11 (PTB11); also elsewhere on the board
SDI: U23.E10 (PTB16); also elsewhere on the board
SDO: U23.E9 (PTB17); also elsewhere on the board
TX: U23.A11 (PTC3); also elsewhere on the board
V_BAT: U3.1; also elsewhere on the board
nCS: U23.E12 (PTB10); also elsewhere on the board

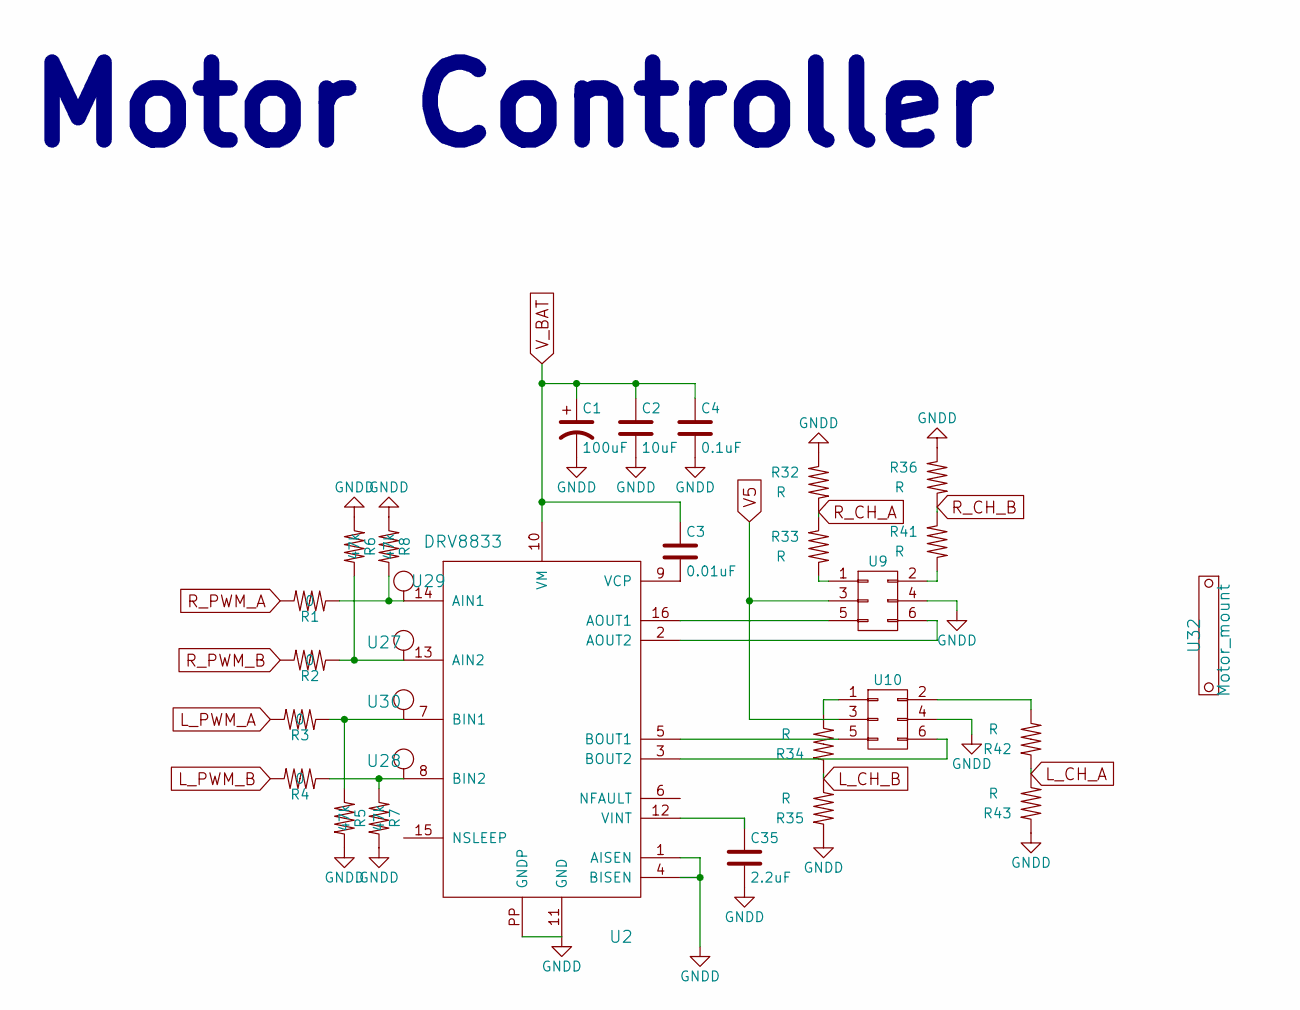
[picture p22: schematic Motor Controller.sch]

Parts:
C1: 100uF
C2: 10uF; C_0805
C3: 0.01uF
C4: 0.1uF; C_0603
C35: 2.2uF; C_0402
R1, R2, R4: 0; C_0402
R3: 0; R_0402
R5, R6, R7, R8: 47k; C_0402
R32, R33, R34, R35, R36, R41, R42, R43: R; C_0402
U2: DRV8833
U9, U10: CONN_02X03
U27, U28, U29, U30: Test_Point
U32: Motor_mount

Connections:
GNDD: C1.2, C2.2, C4.2, C35.2, R5.2, R6.1, R7.2, R8.1, R32.2, R35.2, R36.2, R43.2, U2.1 (AISEN), U2.4 (BISEN), U2.11 (GND), U2.PP (GNDP), U9.4, U10.4; also elsewhere on the board
L_CH_A: R42.2, R43.1; also elsewhere on the board
L_CH_B: R34.2, R35.1; also elsewhere on the board
L_PWM_A: R3.2; also elsewhere on the board
L_PWM_B: R4.2; also elsewhere on the board
unnamed: C3.2, U2.9 (VCP)
unnamed: C35.1, U2.12 (VINT)
unnamed: R1.1, R8.2, U2.14 (AIN1), U29.1
unnamed: R2.1, R6.2, U2.13 (AIN2), U27.1
unnamed: R3.1, R5.1, U2.7 (BIN1), U30.1
unnamed: R4.1, R7.1, U2.8 (BIN2), U28.1
unnamed: R33.1, U9.1
unnamed: R34.1, U10.1
unnamed: R41.1, U9.2
unnamed: R42.1, U10.2
unnamed: U2.2 (AOUT2), U9.6
unnamed: U2.16 (AOUT1), U9.5
unnamed: U2.5 (BOUT1), U10.5
unnamed: U2.3 (BOUT2), U10.6
R_CH_A: R32.1, R33.2; also elsewhere on the board
R_CH_B: R36.1, R41.2; also elsewhere on the board
R_PWM_A: R1.2; also elsewhere on the board
R_PWM_B: R2.2; also elsewhere on the board
V5: U9.3, U10.3; also elsewhere on the board
V_BAT: C1.1, C2.1, C3.1, C4.1, U2.10 (VM); also elsewhere on the board

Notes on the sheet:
Motor Controller

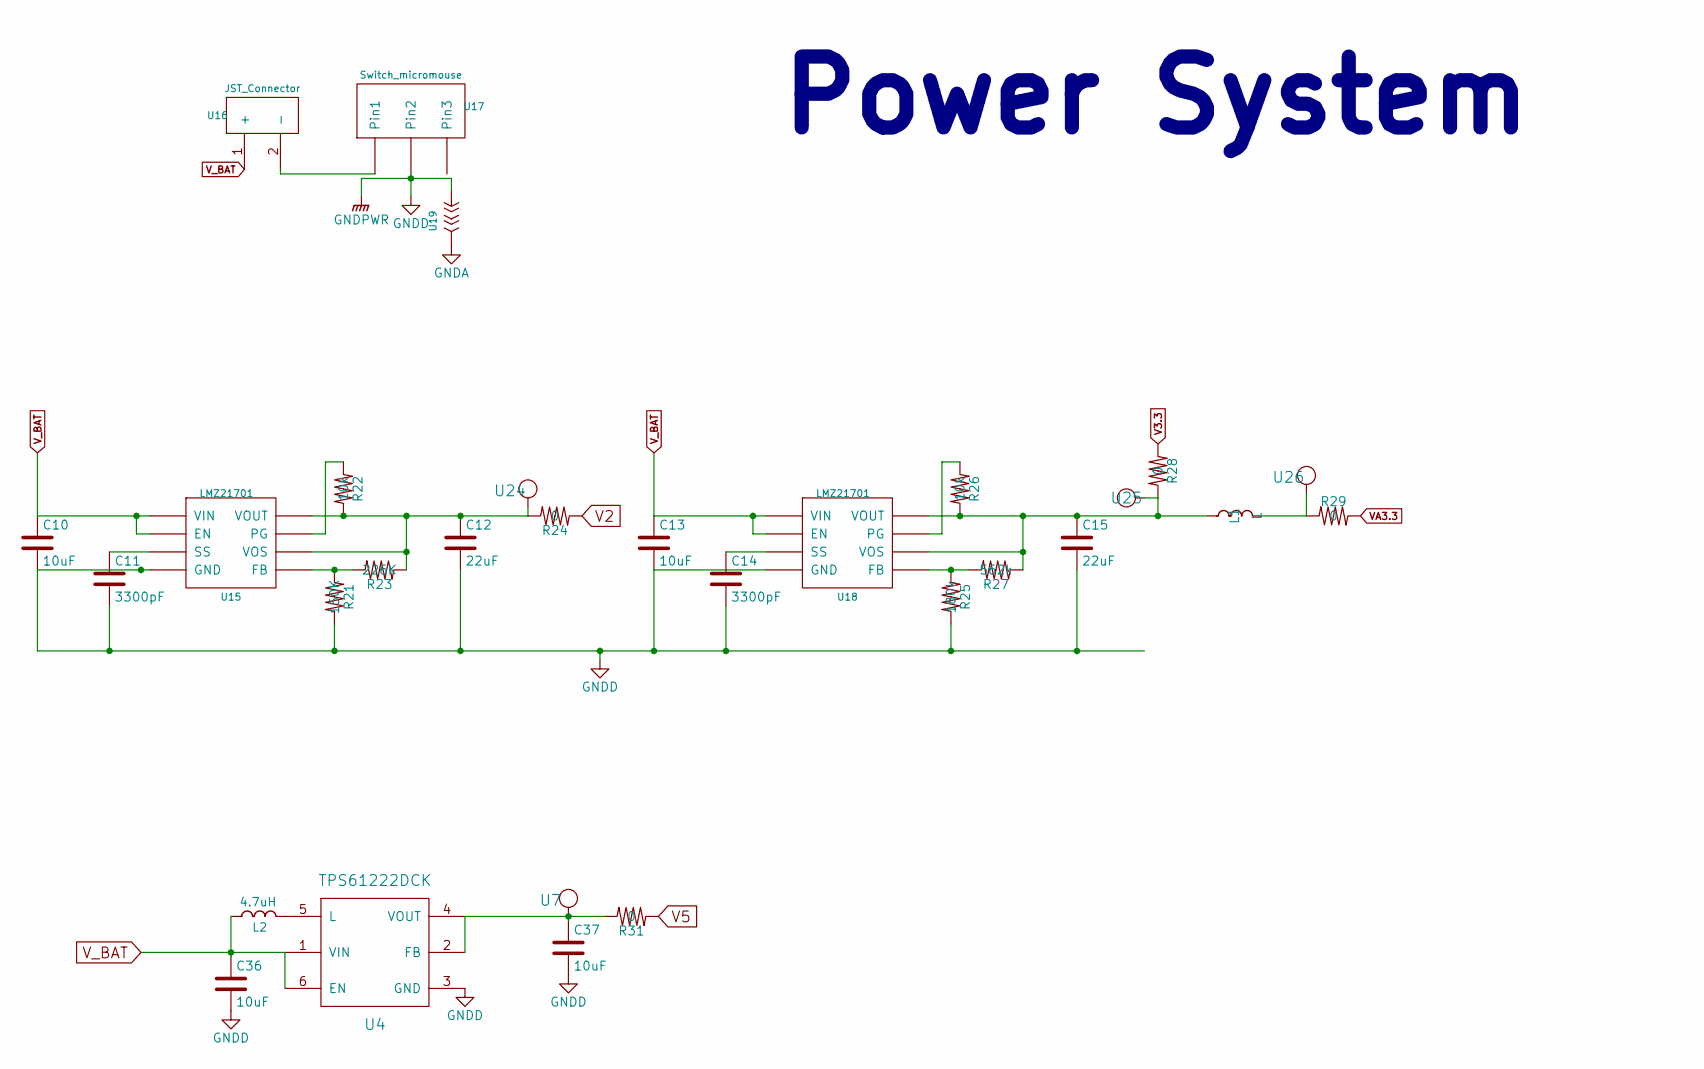
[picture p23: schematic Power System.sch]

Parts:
C10: 10uF; R_0805
C11, C14: 3300pF; C_0402
C12: 22uF; R_0805
C13, C37: 10uF; C_0805
C15: 22uF; C_0805
C36: 10uF; C_0603
L1: L; L_0603
L2: 4.7uH; Neosid_Inductor_SM-NE29_SMD1008
R21: 150K; R_0402
R22, R26: 10k; R_0402
R23: 226K; R_0402
R24, R28, R29, R31: 0; R_0603
R25: 180k; R_0603
R27: 562k; R_0402
U4: TPS61222DCK
U7, U24, U25, U26: Test_Point
U15, U18: LMZ21701
U16: JST_Connector
U17: Switch_micromouse; Switch_battery
U19: splitter; spliter

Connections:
GNDA: U19.2; also elsewhere on the board
GNDD: C10.2, C11.2, C12.2, C13.2, C14.2, C15.2, C36.2, C37.2, R21.2, R25.2, U4.3 (GND), U15.5 (GND), U17.2 (Pin2), U18.5 (GND), U19.1; also elsewhere on the board
unnamed: C11.1, U15.1 (SS)
unnamed: C12.1, R22.2, R23.1, R24.2, U15.4 (VOUT), U15.6 (VOS), U24.1
unnamed: C14.1, U18.1 (SS)
unnamed: C15.1, L1.1, R26.2, R27.1, R28.2, U18.4 (VOUT), U18.6 (VOS), U25.1
unnamed: C37.1, R31.2, U4.2 (FB), U4.4 (VOUT), U7.1
unnamed: L1.2, R29.1, U26.1
unnamed: L2.2, U4.5 (L)
unnamed: R21.1, R23.2, U15.2 (FB)
unnamed: R22.1, U15.3 (PG)
unnamed: R25.1, R27.2, U18.2 (FB)
unnamed: R26.1, U18.3 (PG)
unnamed: U16.2 (-), U17.1 (Pin1)
V2: R24.1; also elsewhere on the board
V3.3: R28.1
V5: R31.1; also elsewhere on the board
VA3.3: R29.2; also elsewhere on the board
V_BAT: C10.1, C13.1, C36.1, L2.1, U4.1 (VIN), U4.6 (EN), U15.7 (EN), U15.8 (VIN), U16.1 (+), U18.7 (EN), U18.8 (VIN); also elsewhere on the board

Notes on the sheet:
Power System

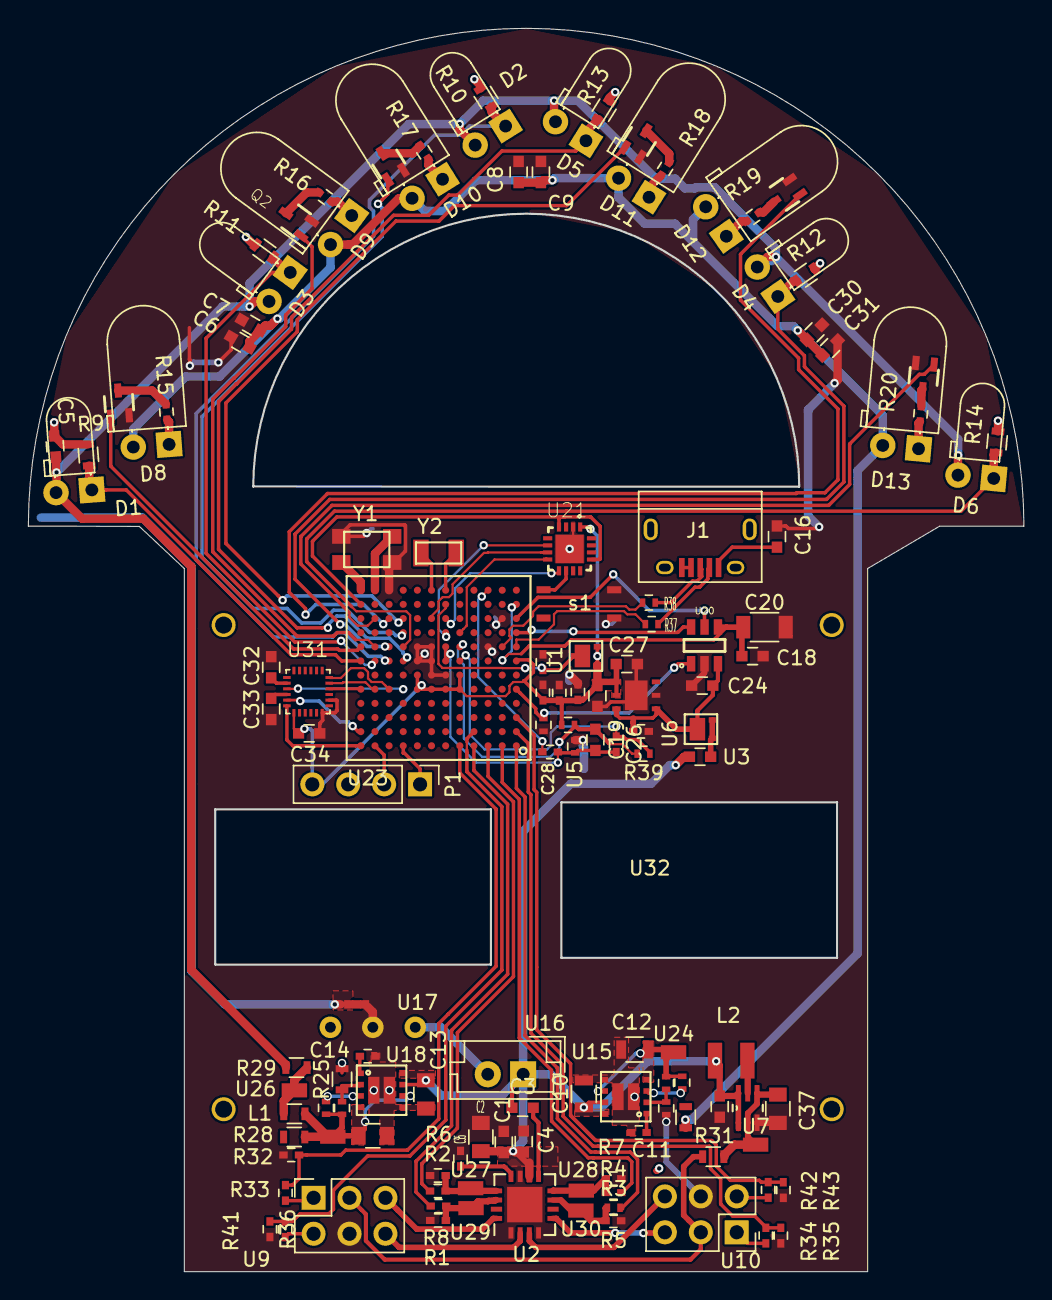
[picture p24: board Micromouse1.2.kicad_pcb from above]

Board: 2 copper layers, 70.4 x 87.9 mm, 132 parts (0 on the bottom side), 102 nets.

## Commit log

2017-06-06 Created the Motor Controller schematic
    Added
    -motor controller schematic
    -Tc442, the H-brigh and 2X3 header library
    [Untitled.kicad_pcb, Untitled.sch, _saved_Untitled.sch]
2017-06-18 Created teensy schematics
    -added MK66FX1M0 schematic
    -added LP38691 linear regulator
    -added PMEG4010CPA
    [IR Emitter .sch, IR Reciver.sch, Micro controller.sch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]
2017-06-20 started wiring up the teensy schematic
    [Micro controller.sch, Micromouse1.2.sch]
2017-06-21 finished the microcontroller connection
    Finished the microcontrollers wiring up with out the pins.
    [Micro controller.sch]
2017-06-22 changed the spliter simbole
    [Power System.sch]
2017-06-22 Motor Ground, isolation resistor
    I added the Motor ground symbols instead of using global label for
    clarity. I also added double to 0 ohm resistors for isolation purposes.
    [_saved_Motor Controller.sch, _saved_Power System.sch]
2017-06-23 Created footprint for DC DC converter
    [Motor Controller.sch, Power System.sch, _saved_Motor Controller.sch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]
2017-06-23 created footprint for linear requlator
    added footprint for microcontroller linear requlator
    [IR Emitter .sch, IR Reciver.sch, Micro controller.sch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]
2017-06-27 Added data sheets
    Added data she for
    - teensy diode
    - 5V linear voltage regulator
    - motor 2x3 header
    -teensy ferrite
    -leds
    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
    [Micro controller.sch]
2017-07-08 added more footprints
    added more footprints such as the microcontroller programer and voltage regualtor
2017-07-09 temp commit
    [Micro controller.sch]
2017-07-25 fixed the mergre conflicts from the adding datasheet commite
    [IR Emitter .sch, IR Reciver.sch]
2017-07-25 added IR-Emitter and IR_Reciver footprint
2017-07-25 resotred micro controller schematic to the older complited version
    [Micro controller.sch]
2017-07-28 Added footprints for diode and both 16MHz and 32.678Mhz crystal
    [IR Emitter .sch]
2017-08-01 added Bluetooth schmatic
    [BlueToothF.sch, IR Emitter .sch, IR Reciver.sch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]
2017-08-01 removed SD Card
    [IR Emitter .sch, Micro controller.sch, Motor Controller.sch]
2017-08-02 generated a netlist
    filled the teensy components with 0402 size untill i find out more info.
    Starting to do PCB layout.
    [Micro controller.sch, Motor Controller.sch, Power System.sch]
2017-09-03 Added MPU-6500
    [BlueToothF.sch, Gyro.sch, IR Emitter .sch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]
2017-09-24 finished floor planning
    -replaced the TC4427 and H brige by a single DRV8833 chip
    [2x5x2.5BallBearing.STEP, 2x5x2.5BallBearing.ipt, BlueToothF.sch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]
2017-10-08 made 3D wheel and Tire setup
    [2x5x2.5BallBearing.0001.ipt, 2x5x2.5BallBearing.0002.ipt, 2x5x2.5BallBearing.STEP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]
2017-10-19 Change of direction
    - I am changing my MCU from mk66fx1m0vmd18 to mk20dx256vlh7 as the QFN package pcb layout is too expensive to manufacture and the 144 LQFP is takes too much real estate
    [BlueToothF.sch, Gyro.sch, IR Emitter .sch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]
2017-10-25 added TPS61222DCK boost converter
    -added TPS61222DCK boost converter for 5V input of the encoder
    [BlueToothF.sch, IR Emitter .sch, Micro controller.sch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]
2017-10-25 layedout the boost converter
    -layedout the boost converter
    -rearranged the motor controller layout
    -cuted some pcb from the center front to reduce the weight(lower weight higher turn speed)
    [BlueToothF.sch, Gyro.sch, IR Emitter .sch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]
2017-10-26 wired up the MCU
    -wired up the mcu to the gyro, motor controller.
    [BlueToothF.sch, Gyro.sch, IR Emitter .sch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]
2017-12-09 Rev 1.0 done
    [BlueToothF.sch, Gyro.sch, Gyro_MPU_6500_test_hardware.kicad_pcb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]
2017-12-09 added isolated island underneath the 16Mhz Crystal
    [Micromouse1.2.kicad_pcb]
2017-12-29 fixed the unconnected teensy bootloader chip
    [BlueToothF.sch, Gyro.sch, IR Emitter .sch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]
2018-01-06 Fixed the broken 2Volt regulator output
    [Micromouse1.2.kicad_pcb, _saved_Micro controller.sch]
